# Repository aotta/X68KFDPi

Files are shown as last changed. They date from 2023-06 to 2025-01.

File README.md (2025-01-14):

# X68KFDPi
Sharp X68000 Floppy disk adapter based on Raspberry Pico(C)

addedd v.1.1: (last night build) - it should improve reading signals and avoid pressing button when floppy inserted (work in progress, for testing purpouse only!)

Use 2 buttons to give X68k the insert/eject signals: you have to eject the virtual floppy (turn off green led) when led flashes, select the image on HxC/Gotek, then re-insert the virtual floppy (Green led re-turned on).
This for disk 1 or 2, as needed.
Now it works for all games i tested so far, but led blinking is not fully supported

Note: use only 74LVC245 IC on your adapter, other type of 74XX245 logic IC may damage your Raspberry!

More info on nfg.forums : [X68KFDUINO - new adapter for external Floppy Drive for HxC & Gotek
](https://nfggames.com/forum2/index.php?topic=7225.0)

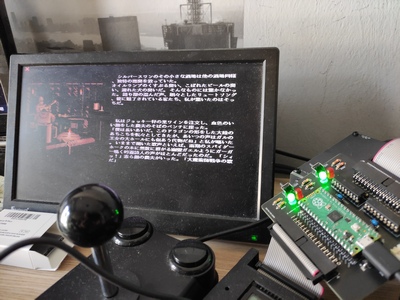
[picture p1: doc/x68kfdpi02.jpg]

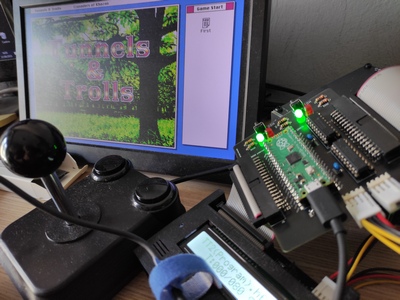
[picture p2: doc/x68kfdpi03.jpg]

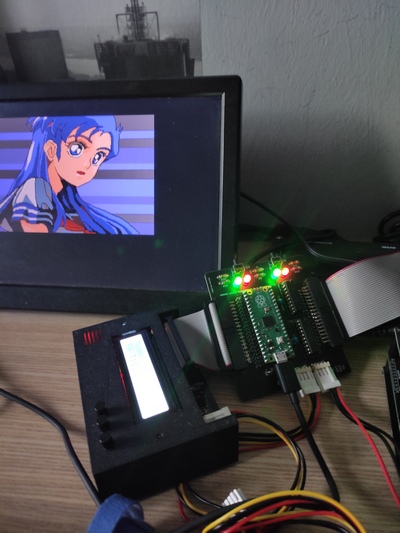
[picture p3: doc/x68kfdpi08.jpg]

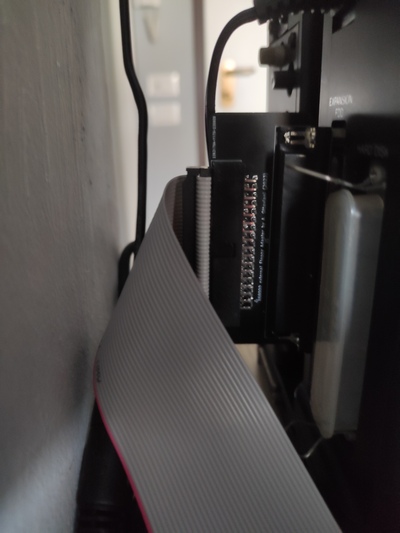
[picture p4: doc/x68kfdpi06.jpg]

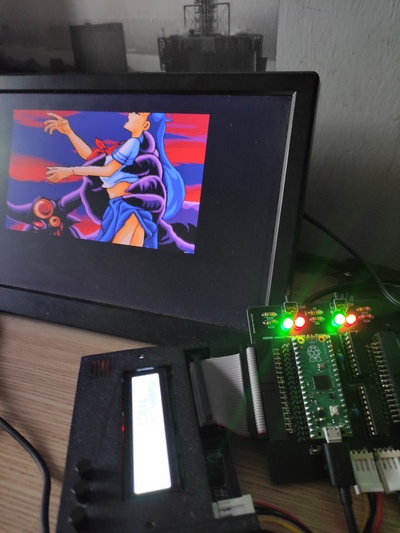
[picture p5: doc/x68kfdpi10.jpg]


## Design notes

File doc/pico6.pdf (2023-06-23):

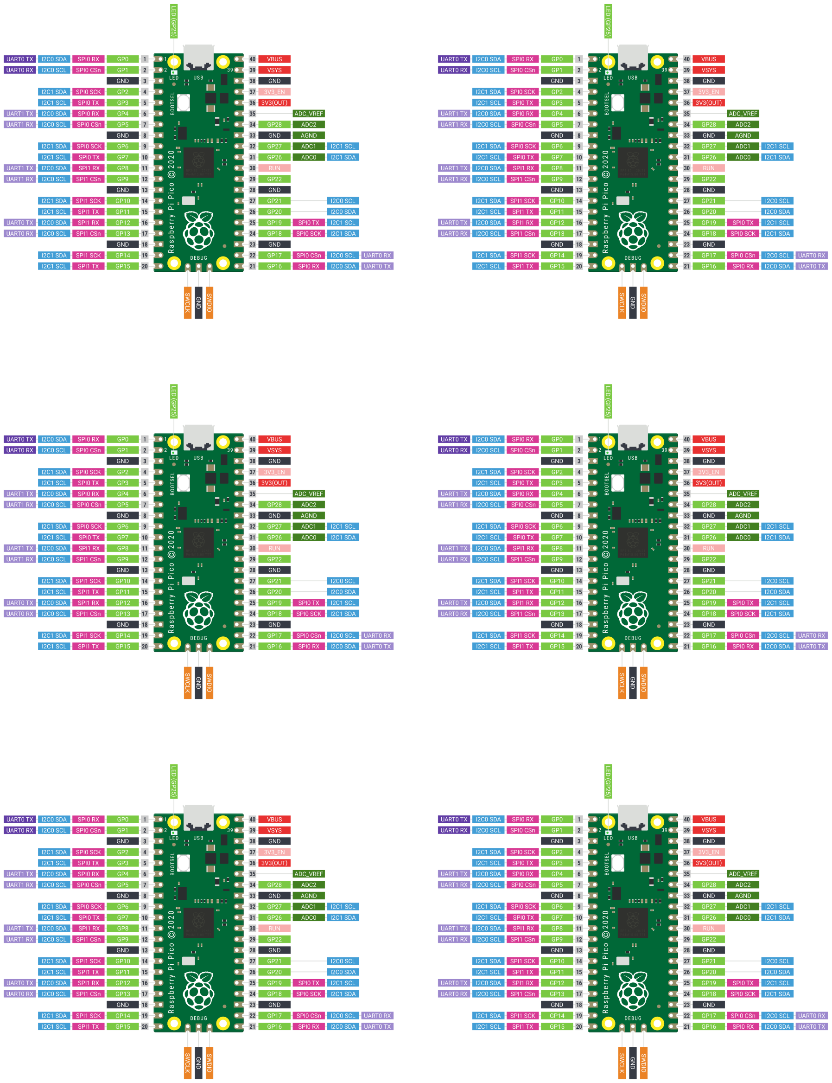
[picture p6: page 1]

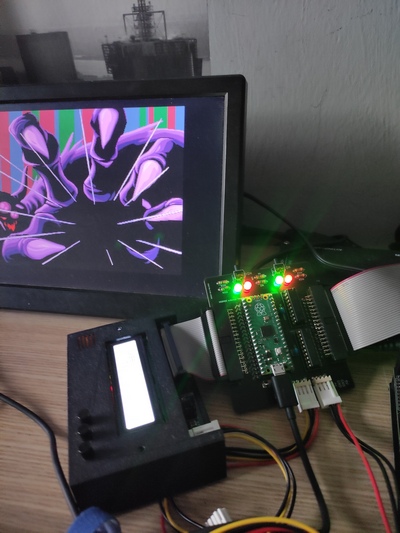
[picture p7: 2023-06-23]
doc/x68kfdpi09.jpg

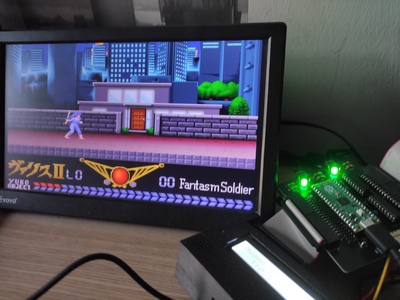
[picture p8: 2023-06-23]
doc/x68kfdpi04.jpg

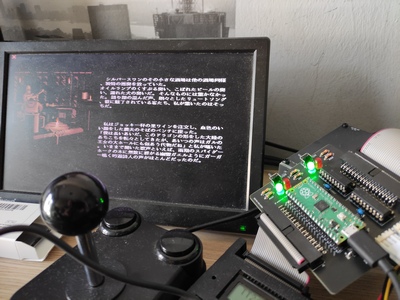
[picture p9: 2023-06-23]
doc/x68kfdpi01.jpg

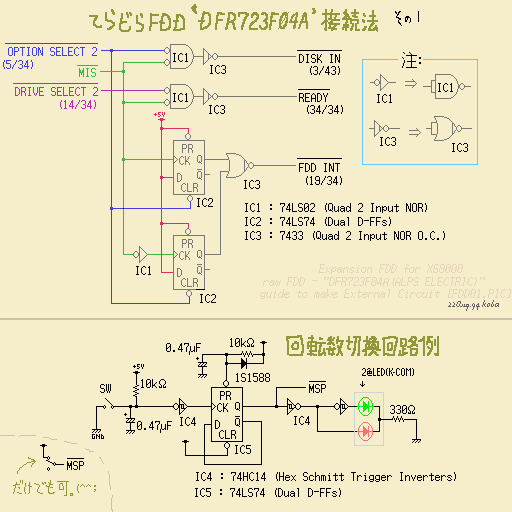
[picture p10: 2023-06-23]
doc/circuit.gif

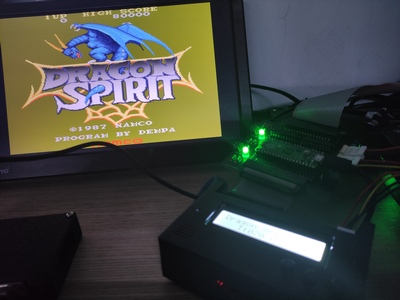
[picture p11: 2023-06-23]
doc/x68kfdpi07.jpg

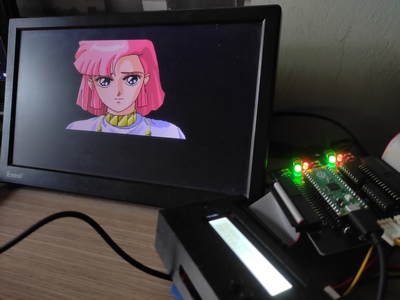
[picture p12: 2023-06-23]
doc/x68kfdpi05.jpg

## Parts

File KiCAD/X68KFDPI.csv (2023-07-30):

Source: | C:\Users\Andrea\Documents\Retrocomputer\Sharp\X68000\X68KFDPI\KiCAD\X68KFDPI.kicad_sch
Date: | 30/07/2023 13:48:27
Tool: | Eeschema (6.0.6)
Generator: | C:\Program Files\KiCad\6.0\bin\scripting\plugins\bom_csv_grouped_by_value.py
Component Count: | 22
Collated Components:
Item | Qty | Reference(s) | Value | LibPart | Footprint | Datasheet
1 | 2 | C1, C2 | 100nF | Device:C | Capacitor_THT:C_Disc_D3.8mm_W2.6mm_P2.50mm | ~
2 | 4 | D1, D2, D3, D4 | LED | Device:LED | LED_THT:LED_D3.0mm | ~
3 | 1 | D5 | D_Schottky | Device:D_Schottky | Diode_THT:D_DO-15_P12.70mm_Horizontal | ~
4 | 1 | J1 | HxC Connector | Connector_Generic:Conn_02x17_Odd_Even | Connector_IDC:IDC-Header_2x17_P2.54mm_Horizontal | ~
5 | 1 | J2 | FD Ext Connector | Connector_Generic:Conn_02x17_Odd_Even | Connector_IDC:IDC-Header_2x17_P2.54mm_Horizontal | ~
6 | 1 | J8 | FloppyPWR | Connector_Generic:Conn_01x04 | Connector_PinHeader_2.54mm:PinHeader_1x04_P2.54mm_Horizontal | ~
7 | 1 | J15 | BrdPWR | Connector_Generic:Conn_01x04 | Connector_PinHeader_2.54mm:PinHeader_1x04_P2.54mm_Horizontal | ~
8 | 4 | R1, R2, R3, R4 | R330 | Device:R | Resistor_THT:R_Axial_DIN0207_L6.3mm_D2.5mm_P7.62mm_Horizontal | ~
9 | 2 | R5, R6 | 10k | Device:R | Resistor_THT:R_Axial_DIN0207_L6.3mm_D2.5mm_P7.62mm_Horizontal | ~
10 | 2 | SW1, SW2 | SW_Push | Switch:SW_Push | Button_Switch_THT:SW_Tactile_SPST_Angled_PTS645Vx83-2LFS | ~
11 | 1 | U1 | Pico | MCU_RaspberryPi_and_Boards:Pico | MCU_RaspberryPi_and_Boards:RPi_Pico_SMD_TH
12 | 2 | U2, U3 | 74LVC245 | 74xx:74LS245 | Package_DIP:DIP-20_W7.62mm_Socket | http://www.ti.com/lit/gpn/sn74LS245

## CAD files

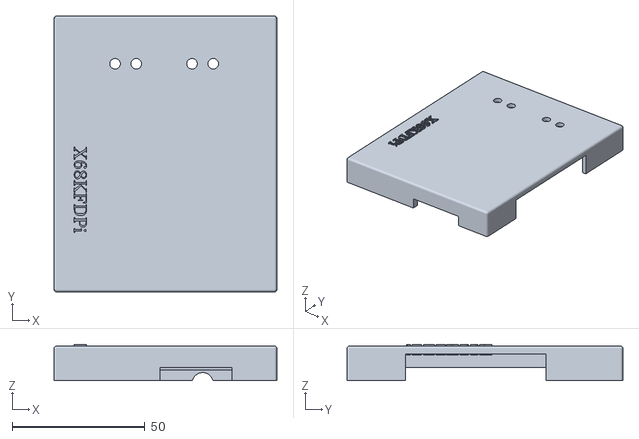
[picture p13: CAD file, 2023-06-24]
3DPrint/X68KFDPi-Top_Print.stl
84.0 x 104.0 x 13.6

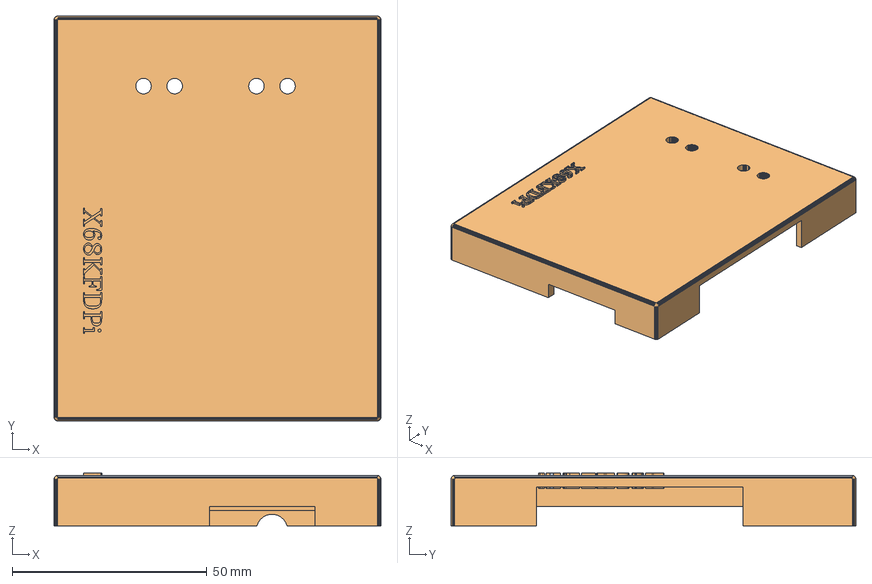
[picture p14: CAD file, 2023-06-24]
3DPrint/X68KFDPi.FCStd
84.0 x 104.0 x 13.6 mm
Top
Top_Print
Top (Meshed)

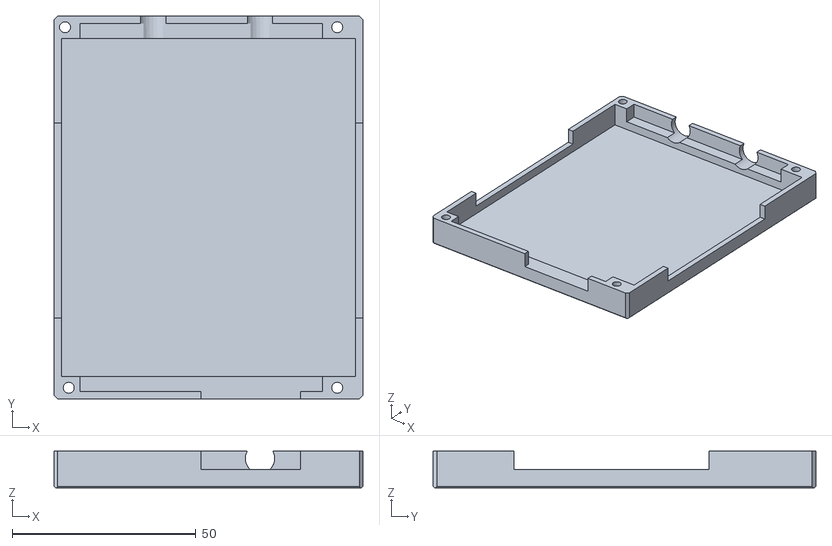
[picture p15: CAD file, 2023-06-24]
3DPrint/X68KFDPi-Bottom_Print.stl
84.0 x 104.0 x 10.0

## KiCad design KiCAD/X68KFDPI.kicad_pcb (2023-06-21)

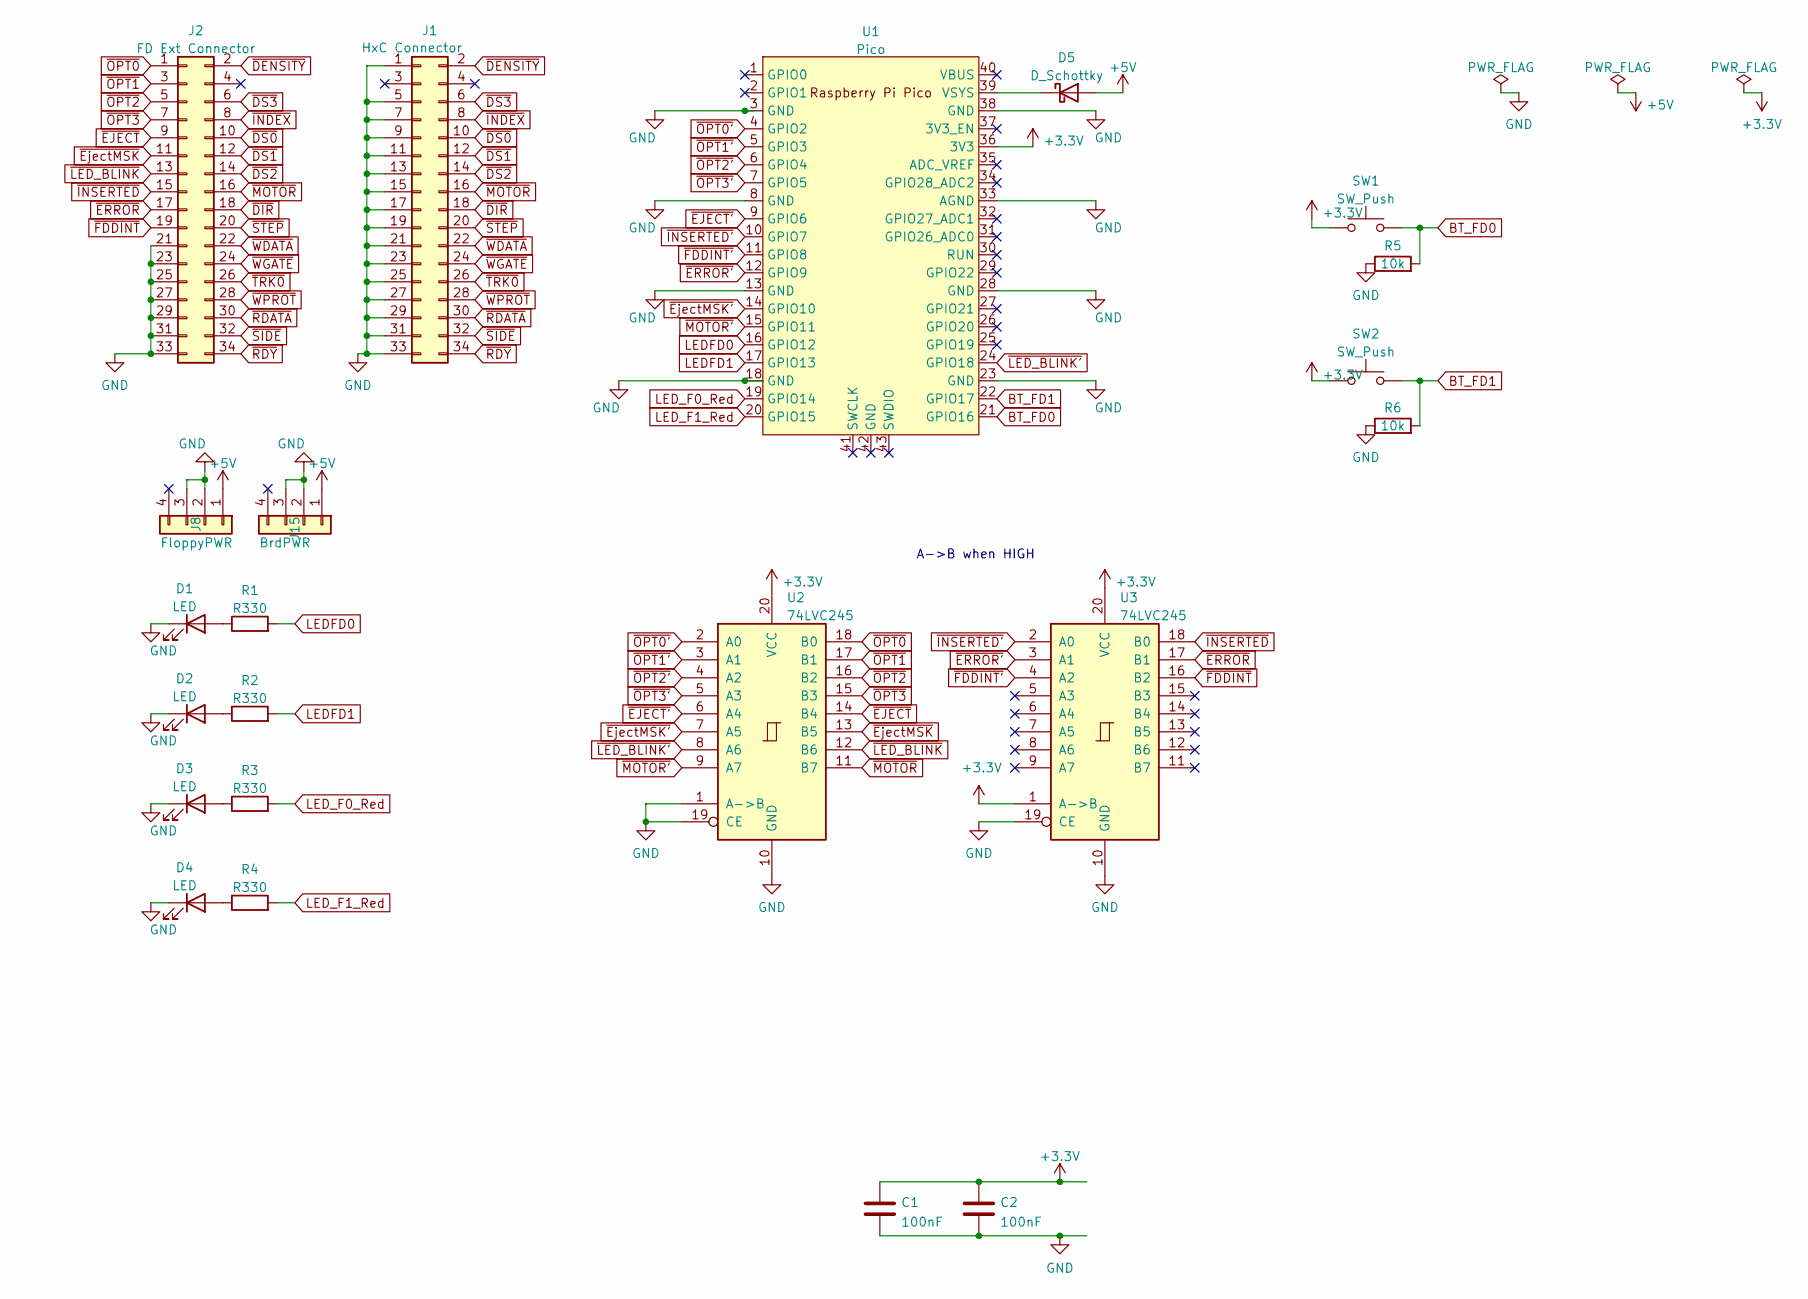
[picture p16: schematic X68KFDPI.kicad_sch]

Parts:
C1, C2: 100nF; C_Disc_D3.8mm_W2.6mm_P2.50mm
D1, D2, D3, D4: LED; LED_D3.0mm
D5: D_Schottky; D_DO-15_P12.70mm_Horizontal
J1: HxC Connector; IDC-Header_2x17_P2.54mm_Horizontal
J2: FD Ext Connector; IDC-Header_2x17_P2.54mm_Horizontal
J8: FloppyPWR; PinHeader_1x04_P2.54mm_Horizontal
J15: BrdPWR; PinHeader_1x04_P2.54mm_Horizontal
R1, R2, R3, R4: R330; R_Axial_DIN0207_L6.3mm_D2.5mm_P7.62mm_Horizontal
R5, R6: 10k; R_Axial_DIN0207_L6.3mm_D2.5mm_P7.62mm_Horizontal
SW1, SW2: SW_Push; SW_Tactile_SPST_Angled_PTS645Vx83-2LFS
U1: Pico; RPi_Pico_SMD_TH
U2, U3: 74LVC245; DIP-20_W7.62mm_Socket

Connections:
+3.3V: C1.1, C2.1, SW1.1, SW2.1, U1.36 (3V3), U2.20 (VCC), U3.1 (A->B), U3.20 (VCC)
+5V: D5.2 (A), J8.1, J15.1
BT_FD0: R5.2, SW1.2, U1.21 (GPIO16)
BT_FD1: R6.2, SW2.2, U1.22 (GPIO17)
GND: C1.2, C2.2, D1.1 (K), D2.1 (K), D3.1 (K), D4.1 (K), J1.1, J1.5, J1.7, J1.9, J1.11, J1.13, J1.15, J1.17, J1.19, J1.21, J1.23, J1.25, J1.27, J1.29, J1.31, J1.33, J2.21, J2.23, J2.25, J2.27, J2.29, J2.31, J2.33, J8.2, J8.3, J15.2, J15.3, R5.1, R6.1, U1.3 (GND), U1.8 (GND), U1.13 (GND), U1.18 (GND), U1.23 (GND), U1.28 (GND), U1.33 (AGND), U1.38 (GND), U2.1 (A->B), U2.10 (GND), U2.19 (CE), U3.10 (GND), U3.19 (CE)
LEDFD0: R1.2, U1.16 (GPIO12)
LEDFD1: R2.2, U1.17 (GPIO13)
LED_F0_Red: R3.2, U1.19 (GPIO14)
LED_F1_Red: R4.2, U1.20 (GPIO15)
unnamed: D1.2 (A), R1.1
unnamed: D2.2 (A), R2.1
unnamed: D3.2 (A), R3.1
unnamed: D4.2 (A), R4.1
unnamed: D5.1 (K), U1.39 (VSYS)
~DENSITY: J1.2, J2.2
~DIR: J1.18, J2.18
~DS0: J1.10, J2.10
~DS1: J1.12, J2.12
~DS2: J1.14, J2.14
~DS3: J1.6, J2.6
~EJECT': U1.9 (GPIO6), U2.6 (A4)
~EJECT: J2.9, U2.14 (B4)
~ERROR': U1.12 (GPIO9), U3.3 (A1)
~ERROR: J2.17, U3.17 (B1)
~EjectMSK': U1.14 (GPIO10), U2.7 (A5)
~EjectMSK: J2.11, U2.13 (B5)
~FDDINT': U1.11 (GPIO8), U3.4 (A2)
~FDDINT: J2.19, U3.16 (B2)
~INDEX: J1.8, J2.8
~INSERTED': U1.10 (GPIO7), U3.2 (A0)
~INSERTED: J2.15, U3.18 (B0)
~LED_BLINK': U1.24 (GPIO18), U2.8 (A6)
~LED_BLINK: J2.13, U2.12 (B6)
~MOTOR': U1.15 (GPIO11), U2.9 (A7)
~MOTOR: J1.16, J2.16, U2.11 (B7)
~OPT0': U1.4 (GPIO2), U2.2 (A0)
~OPT0: J2.1, U2.18 (B0)
~OPT1': U1.5 (GPIO3), U2.3 (A1)
~OPT1: J2.3, U2.17 (B1)
~OPT2': U1.6 (GPIO4), U2.4 (A2)
~OPT2: J2.5, U2.16 (B2)
~OPT3': U1.7 (GPIO5), U2.5 (A3)
~OPT3: J2.7, U2.15 (B3)
~RDATA: J1.30, J2.30
~RDY: J1.34, J2.34
~SIDE: J1.32, J2.32
~STEP: J1.20, J2.20
~TRK0: J1.26, J2.26
~WDATA: J1.22, J2.22
~WGATE: J1.24, J2.24
~WPROT: J1.28, J2.28

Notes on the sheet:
A->B when HIGH

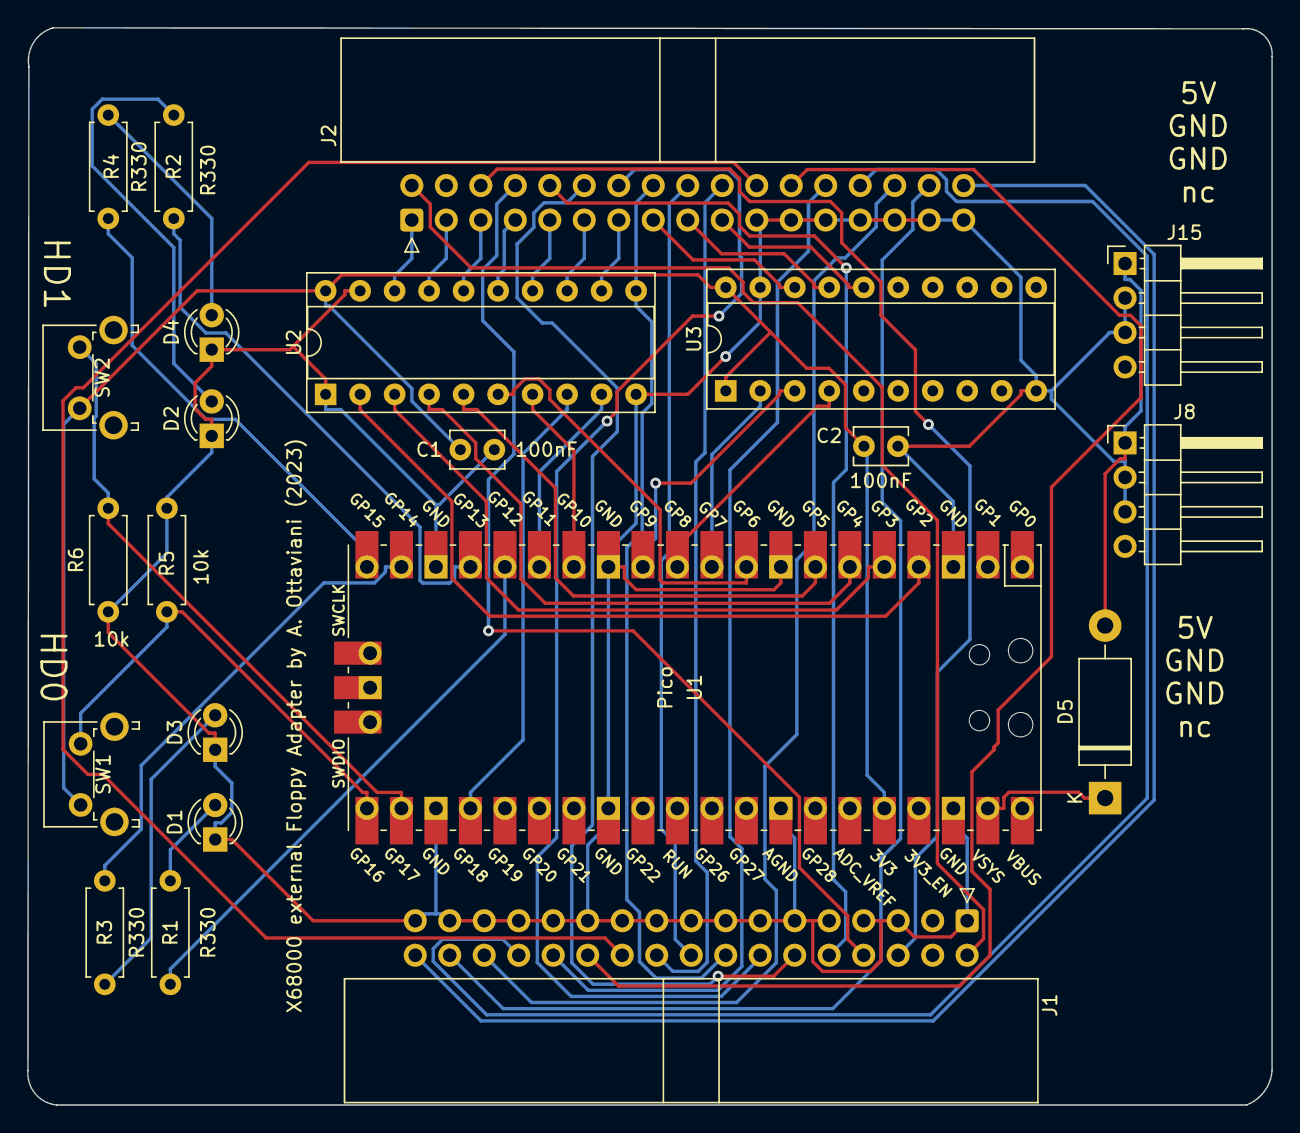
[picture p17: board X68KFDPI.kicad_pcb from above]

Board: 2 copper layers, 91.6 x 79.3 mm, 22 parts (0 on the bottom side), 51 nets.

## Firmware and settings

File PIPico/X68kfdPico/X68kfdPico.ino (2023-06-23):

/*
 * X68KFDINO - External FD adapter for Sharp X68000
 * by Andrea Ottaviani june 2023
 * 
 * 
Access/Write strobe :

/OPTION_SEL_X : "Chip select" for the extra functions of drive DSX (X: 0-3)

Input / functions signals :

/EJECT_FUNC : If this signal is low when OPTION_SEL_X is asserted, the disk will be ejected.
/LOCK_FUNC (Eject MSK?): If this signal is low when OPTION_SEL_X is asserted, the disk will be locked (eject button off). If this signal is high when OPTION_SEL_X is asserted the disk will be unlocked (eject button on).
/BLINK_FUNC : If this signal is low when OPTION_SEL_X is asserted, the LED blink. If this signal is high when OPTION_SEL_X is asserted, the LED stop blinking.

Output signals (drive status):

/DISK_IN_DRIVE : when OPTION_SEL_X is asserted : Low = a disk in the drive. High = No disk.
/INSERT_FAULT : when OPTION_SEL_X is asserted : Low = a disk insert failure occured . High = No problem. This status is cleared at the rising edge of OPTION_SEL_X.

Output signal (Interrupt line):

/INT : Interrupt line : This signal is activated at each disk status change (inserted/ejected). The interrupt is cleared at the rising edge of /OPTION_SEL_X. (Note : more than one drive can activate this line in the same time -> Softwares scan all disk drive at each /INT assertion).

Note 1: For proper operation all output should be able to drive 5/150=33mA since 150 ohms pull-up are used.
Note 2: The X68000 /OPTION_SEL_X assertion duration is ~2.5us per access. This can depend of the software, the CPU speed.
 */


//Cablage
#define OPT0                2  // Set D2 as OPT0 Read strobe
#define OPT1                3  // Set D3 as OPT1 Read strobe
#define OPT2                4  // Set D4 as OPT2 Read strobe
#define OPT3                5  // Set D5 as OPT3 Read strobe
#define Eject               6  // Set D6 as Eject Read strobe
#define Inserted            7  // Set D7 as Inserted Read strobe
#define FDDINT              8  // Set D8 as FD Interrupt Read strobe
#define Error               9  // Set D9 as Error Read strobe
#define EjectMSK           10  // Set D10 as EjectMSK Read strobe
#define Motor              11  // Set D11 as Motor Read strobe
#define LEDFD0             12  // Set D12 as LED FD0 output (Green LED)
#define LEDFD1             13  // Set D13 as LED FD1 output (Green LED)
#define LED_FD0_RED        14  // Set D14 as LED FD0 output (Red LED)
#define LED_FD1_RED        15  // Set D15 as LED FD1 output (Red LED)
#define BT_FD0             16  // Set D16 as Button FD0 Read strobe
#define BT_FD1             17  // Set D17 as Button FD1 Read strobe
#define LED_BLINK          18  // Set A0 as LED (Blink) output


void setup() {
  // put your setup code here, to run once:
  // initialize digital pin 13 as an output.
  pinMode(OPT0, INPUT);
  pinMode(OPT1, INPUT);
  pinMode(OPT2, INPUT);
  pinMode(OPT3, INPUT);
  pinMode(Eject, INPUT);
  pinMode(BT_FD0, INPUT);
  pinMode(BT_FD1, INPUT);
  pinMode(LED_BLINK, INPUT); // Blink
  pinMode(EjectMSK, INPUT); // LOCK (Red led)
  pinMode(Motor, INPUT); // 
  pinMode(Inserted, OUTPUT);
  pinMode(Error, OUTPUT);
  pinMode(FDDINT, OUTPUT);
  pinMode(LEDFD0, OUTPUT);
  pinMode(LEDFD1, OUTPUT);
  pinMode(LED_FD0_RED, OUTPUT); // used for LED LOCK, Red light
  pinMode(LED_FD1_RED, OUTPUT); // used for LED LOCK, Red light
  
  Serial.begin(115200);

}

void loop() {
  unsigned char DF0=1; // 0=eject, 1=insert, 2=lock, 3=blink
  unsigned char DF1=1; // 0=eject, 1=insert, 2=lock, 3=blink
  unsigned char bitBlink=0;
  unsigned short int BlinkCounter=0;
   
  // put your main code here, to run repeatedly:
 Serial.println("Start");
 while(1) {

    BlinkCounter++;
    if (BlinkCounter>=29999) BlinkCounter=0;
    
    if (digitalRead(BT_FD0)) {
       if (DF0==1) {
        DF0=0;
      } else {
        bitBlink=0;
        DF0=1;
       }
    Serial.print("DF0:");Serial.println(DF0);
    delay(200);
    digitalWrite(FDDINT,LOW);
    }

  if (digitalRead(BT_FD1)) {
       if (DF1==1) {
        DF1=0;
      } else {
        bitBlink=0;
        DF1=1;
      }
    Serial.print("DF1:");Serial.println(DF1);
    delay(200);
    digitalWriteFast(FDDINT,LOW);
    }

  if (!digitalReadFast(LED_BLINK)) {
       bitBlink=1;
     // Serial.print("Led Blink");
      }    

  if (!digitalReadFast(OPT0)) {
  
    
     if (!digitalReadFast(Eject)) {
       DF0=0;
       digitalWriteFast(FDDINT,LOW);
    //   Serial.print("Ej 0-");
    }
 
    if (!DF0) {
        digitalWriteFast(LEDFD0,LOW);
        digitalWriteFast(Inserted,HIGH);  // for TT!!        
      } else {
        digitalWriteFast(Inserted,LOW);
         digitalWriteFast(Error,HIGH);  
         digitalWriteFast(FDDINT,HIGH);  // not remove!! 
         digitalWriteFast(LEDFD0,HIGH);
      }

    if (!digitalReadFast(EjectMSK)) {
      digitalWriteFast(LED_FD0_RED,HIGH);
    //   Serial.print("EjMSK 0-");
      } else {
      digitalWriteFast(LED_FD0_RED,LOW);
    }

 }  // opt 0

 if (!digitalReadFast(OPT1)) {
 
  if (!(digitalReadFast(Eject))) {
      DF1=0;
      digitalWriteFast(FDDINT,LOW);
  //    Serial.print("Ej 1-");
    }
     
   if (!DF1) {
        digitalWriteFast(LEDFD1,LOW);
        digitalWriteFast(Inserted,HIGH);  // for TT!!        
      } else {
        digitalWriteFast(Inserted,LOW);
         digitalWriteFast(Error,HIGH);  
         digitalWriteFast(FDDINT,HIGH);  // not remove!! 
         digitalWriteFast(LEDFD1,HIGH);
      }

    if (!digitalReadFast(EjectMSK)) {
      digitalWriteFast(LED_FD1_RED,HIGH);
     // Serial.print("EjMSK 1-");
      } else {
      digitalWriteFast(LED_FD1_RED,LOW);
    }

  } //opt1

  if (bitBlink==1) {
    if (!DF0) {
       Serial.print("b0"); // do not remove, needed for timing

      if (BlinkCounter>=3000) {
        digitalWriteFast(LEDFD0,LOW);
      } else {
        digitalWriteFast(LEDFD0,HIGH);
      }
    }
    if (!DF1) {
      Serial.print("b1"); // do not remove, needed for timing
    if (BlinkCounter>=3000) {
        digitalWriteFast(LEDFD1,LOW);
      } else {
        digitalWriteFast(LEDFD1,HIGH);
      }
    }
  }
  
 } //while
 
}
